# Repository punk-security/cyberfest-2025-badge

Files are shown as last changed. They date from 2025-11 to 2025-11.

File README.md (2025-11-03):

# This is the repo for the CyberNorth CyberFest badge

**This badge was given out at CyberFest conference to all attendees, and had a compass mode so you can always find your way North**

This badge uses UV full colour silk, and we ordered them from JLCPCB using EasyEDA. The PCB was built first with AutoCAD EAGLE, then exported, and imported into EasyEDA by JLCPCB for design updates. We have provided the EasyEDA exports in case you want to import and tweak the designs, or you can order your own as-is using the gerber files :)

Unlike almost all of our other badges, we ordered these partialy assembled. This means that JLCPCB placed some parts for us. We did this as the 3-axis magnometer (which does the compass reading) was tiny and needed a super tiny capacitor too!

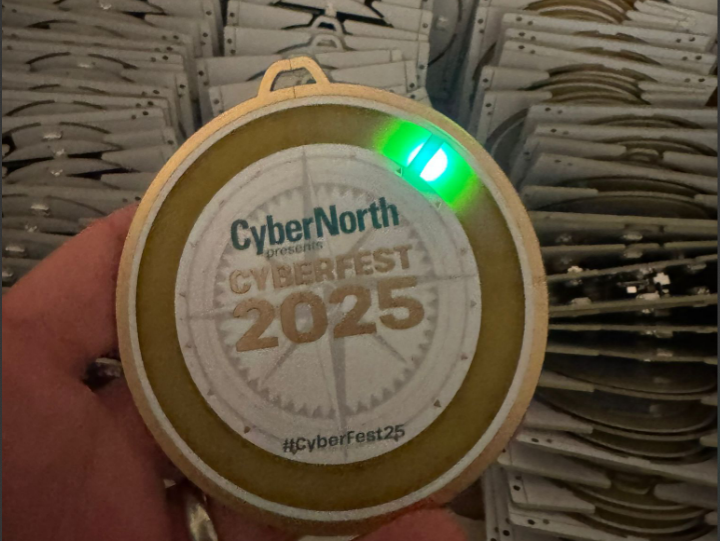
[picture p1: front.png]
PCB Front

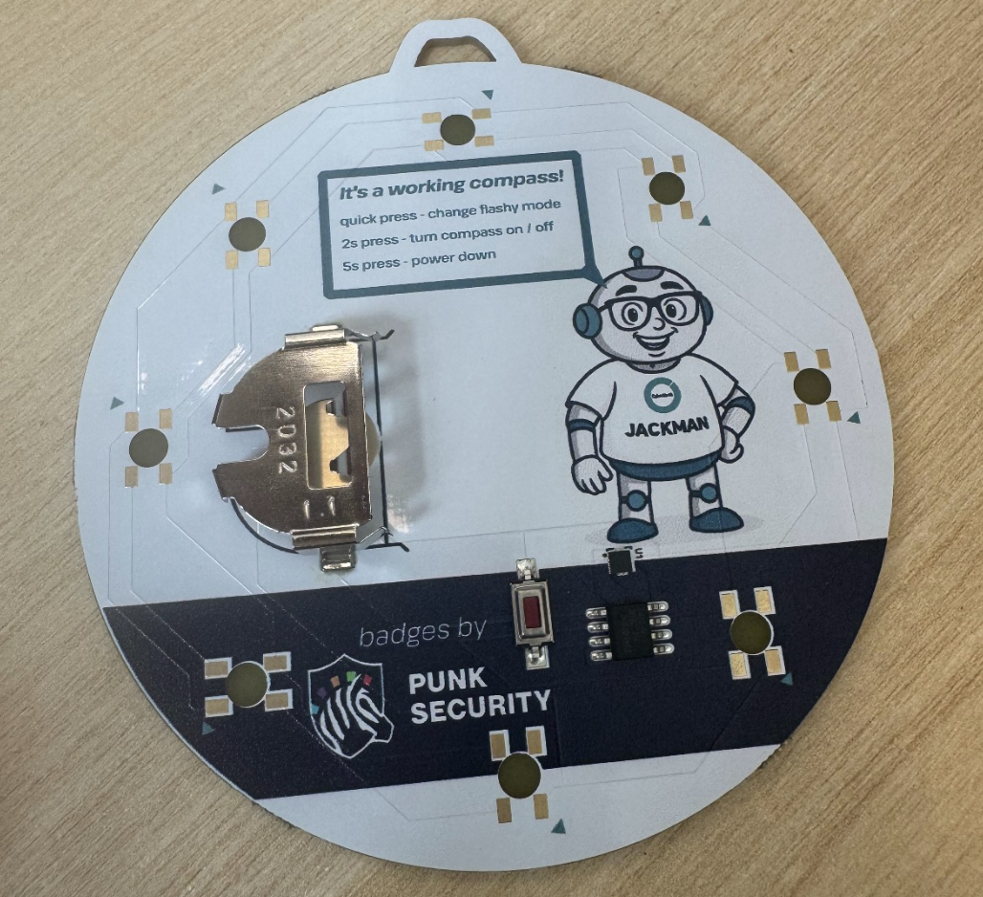
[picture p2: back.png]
PCB Back


Lots of things in this repo:

- EAGLE.brd: The AutoCAD Eagle board design
- EAGLE.sch - The AutoCAD Eagle circuit schematic
- cyberfest-2025.epro - The EasyEDA export, including the front art
- gerber.zip: the file you can upload to JLCPCB and order your own badge, as is
- firmware.ino: the arduino code that powers the badge, which you can modify and flash via the SAO connector

## Bill Of Materials

We sourced some parts direct from JLCPCB, so you may need to tweak footprints when ordering direct. The most notable difference is the coin cell battery clasp, which has smaller "foot" pads. The one provided by JLC was awful and we would recommend replacing it.

Essentially its:

* ATTINY412 microcontroller
* Button - any surface mount button fitting the footprint will work
* CR2032 battery clip  - surface mount not through hole
* Neopixel 5050 addressable LED - Definitely get the right version of these
* LIS2MDLTR - a 3-axis magnetometer (the compass)

## How does it work?

The badge does the usually blinky modes, but also provides a north bearing. To do this, we read the magentic readings from a 3-axis magnometer (LIS2MDLTR)

Compass reading is difficult, as the enviroment is full of intereference. We need to calibrate our readings, so when compass mode is activated we take continous readings for a few seconds. During this time, you should rotate the badge a few times. 

You'll see lots of really tricky code in this repo around compass bearings. Essentially turning magentic readings into a bearing is difficult, and the math to do it takes a lot of flash space. More flash space then we have available actually, so we had to do some funky coding to get a near-enough reading. Our resolution is one of 8 LEDS, so it's a fair trade off!

The current build uses 4082 of 4096 bytes of flash!

## Ordering your own badge

We've uploaded the AutoCAD EAGLE schematic and board design!  You will probably have to do some tweaks to get it working as they're not designed to be standalone exports.

This is then exported to EasyEDA to add the colour print to the boards. The file for that is already in the repo, so you can skip the EAGLE step if you prefer.

We've also uploaded the gerber.zip.  Take this to JLCPCB and you can order your own exact copies of the board :)

## Writing and flashing code!

We use [MegaTinyCore](https://github.com/SpenceKonde/megaTinyCore) for the arduino interface for ATTINY4x2 chips.

Dev and flashing is done within the Arduino IDE ( < v2 ) using a jtag2updi interface, as discussed [here](https://github.com/SpenceKonde/AVR-Guidance/blob/master/UPDI/jtag2updi.md)

We use [these little usb sticks](https://amzn.eu/d/c0lx0wG), with a 4.7k resistor soldered between the Tx and Rx lines.  

### Installing MegaTinyCore dependencies

This board package can be installed via the board manager in arduino. The boards manager URL is:

`http://drazzy.com/package_drazzy.com_index.json`

1. File -> Preferences, enter the above URL in "Additional Boards Manager URLs"
2. Tools -> Boards -> Boards Manager...
3. Wait while the list loads (takes longer than one would expect, and refreshes several times).
4. Select "megaTinyCore by Spence Konde" and click "Install". For best results, choose the most recent version.

### Setting up the IDE

1. Open the file **firmware.ino** in arduino
2. Select tools > Board > megaTinyCore > ATtiny412/402/212/202
3. Select tools > Chip > ATtiny412
4. Select tools > Clock > 16Mhz internal *(we get power issues otherwise)*
5. Select tools > millis > Disabled
5. Select tools > Programmer > SerialUPDI SLOW
6. Select tools > Port > ( pick your COM port)

### Flashing firmware
1. Connect the 3v3 pin to 3v on your usb (maybe wedge it in the battery clip)
2. Connect GND to GND
3. Connect UPDI to the RxD port
4. Click Upload button

## How to solder?

Make sure to line up the dot on the attiny412 with the dot on the board.

*It's much easier if you hold the component in place with one hand, and then solder one pad. Now you can solder the rest of the pads with one hand*

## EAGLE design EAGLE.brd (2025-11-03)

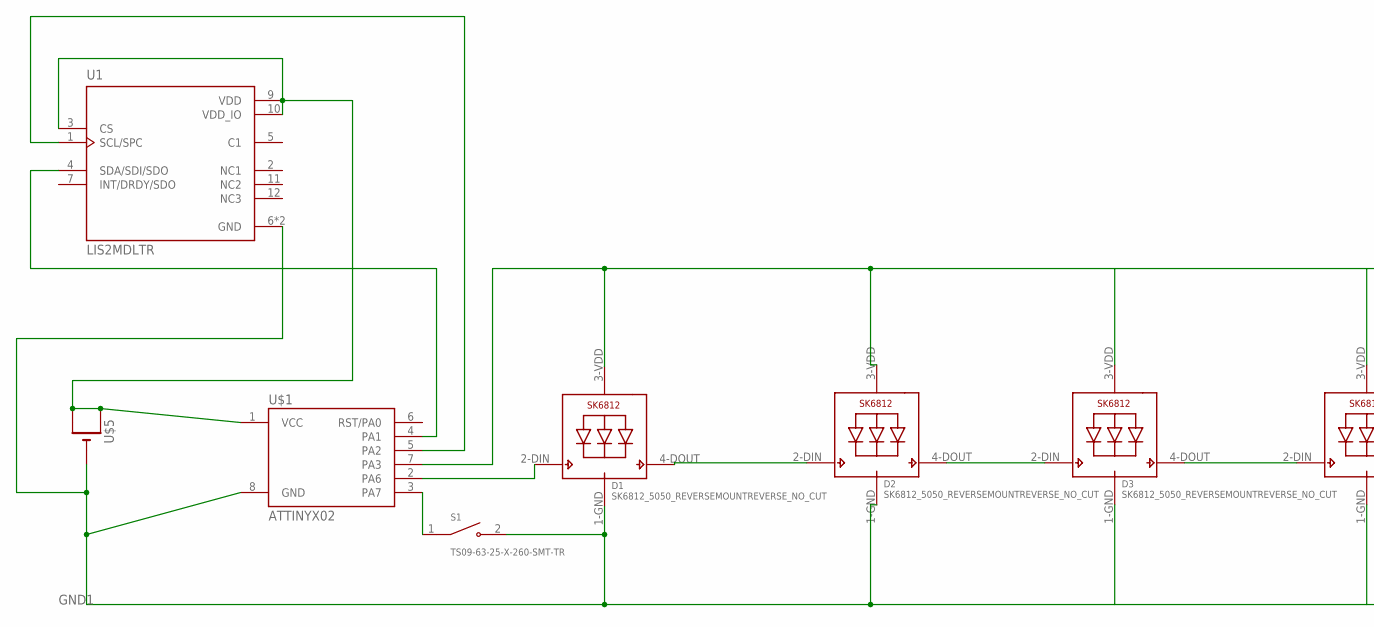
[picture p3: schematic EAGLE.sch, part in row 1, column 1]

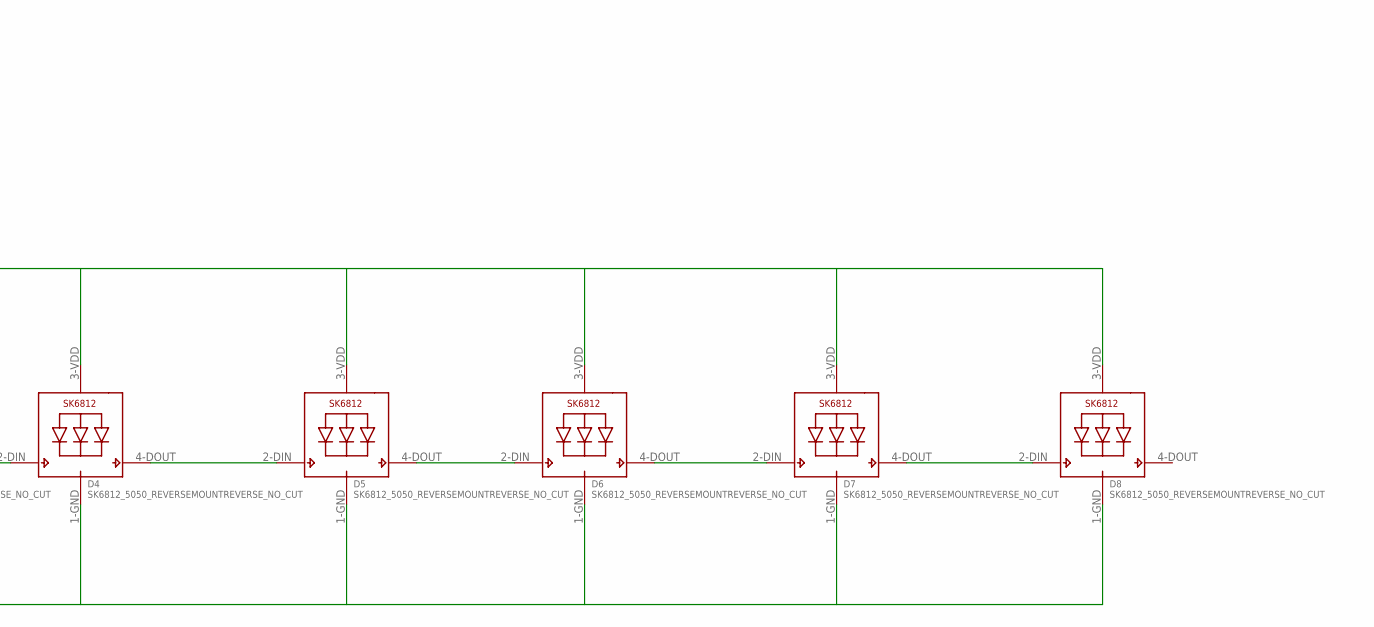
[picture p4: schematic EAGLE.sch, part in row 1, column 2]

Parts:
D1, D2, D3, D4, D5, D6, D7, D8: SK6812_5050_REVERSEMOUNTREVERSE_NO_CUT; SK6812_REVERSE_NO_CUT
S1: TS09-63-25-X-260-SMT-TR; SW_TS09-63-25-X-260-SMT-TR
U1: LIS2MDLTR; PQFN50P200X200X70-12N
U$1: ATTINYX02; SOIC08_JEDEC_150MIL
U$5: CR2032SMT; CR2032-SMD

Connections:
GND1: D1.1-GND (GND), D2.1-GND (GND), D3.1-GND (GND), D4.1-GND (GND), D5.1-GND (GND), D6.1-GND (GND), D7.1-GND (GND), D8.1-GND (GND), S1.2, U1.6 (GND), U1.8 (GND), U$1.8 (GND), U$5.-
unnamed: D1.4-DOUT (DO), D2.2-DIN (DI)
unnamed: D1.2-DIN (DI), U$1.2 (PA6)
unnamed: D3.4-DOUT (DO), D4.2-DIN (DI)
unnamed: D2.4-DOUT (DO), D3.2-DIN (DI)
unnamed: S1.1, U$1.3 (PA7)
unnamed: D4.4-DOUT (DO), D5.2-DIN (DI)
unnamed: D6.4-DOUT (DO), D7.2-DIN (DI)
unnamed: D7.4-DOUT (DO), D8.2-DIN (DI)
unnamed: D5.4-DOUT (DO), D6.2-DIN (DI)
unnamed: U1.1 (SCL/SPC), U$1.5 (PA2)
unnamed: U1.4 (SDA/SDI/SDO), U$1.4 (PA1)
VCC1: U1.3 (CS), U1.9 (VDD), U1.10 (VDD_IO), U$1.1 (VCC), U$5.+$1 (+), U$5.+$2 (+1)
VDD2: D1.3-VDD (VDD), D2.3-VDD (VDD), D3.3-VDD (VDD), D4.3-VDD (VDD), D5.3-VDD (VDD), D6.3-VDD (VDD), D7.3-VDD (VDD), D8.3-VDD (VDD), U$1.7 (PA3)

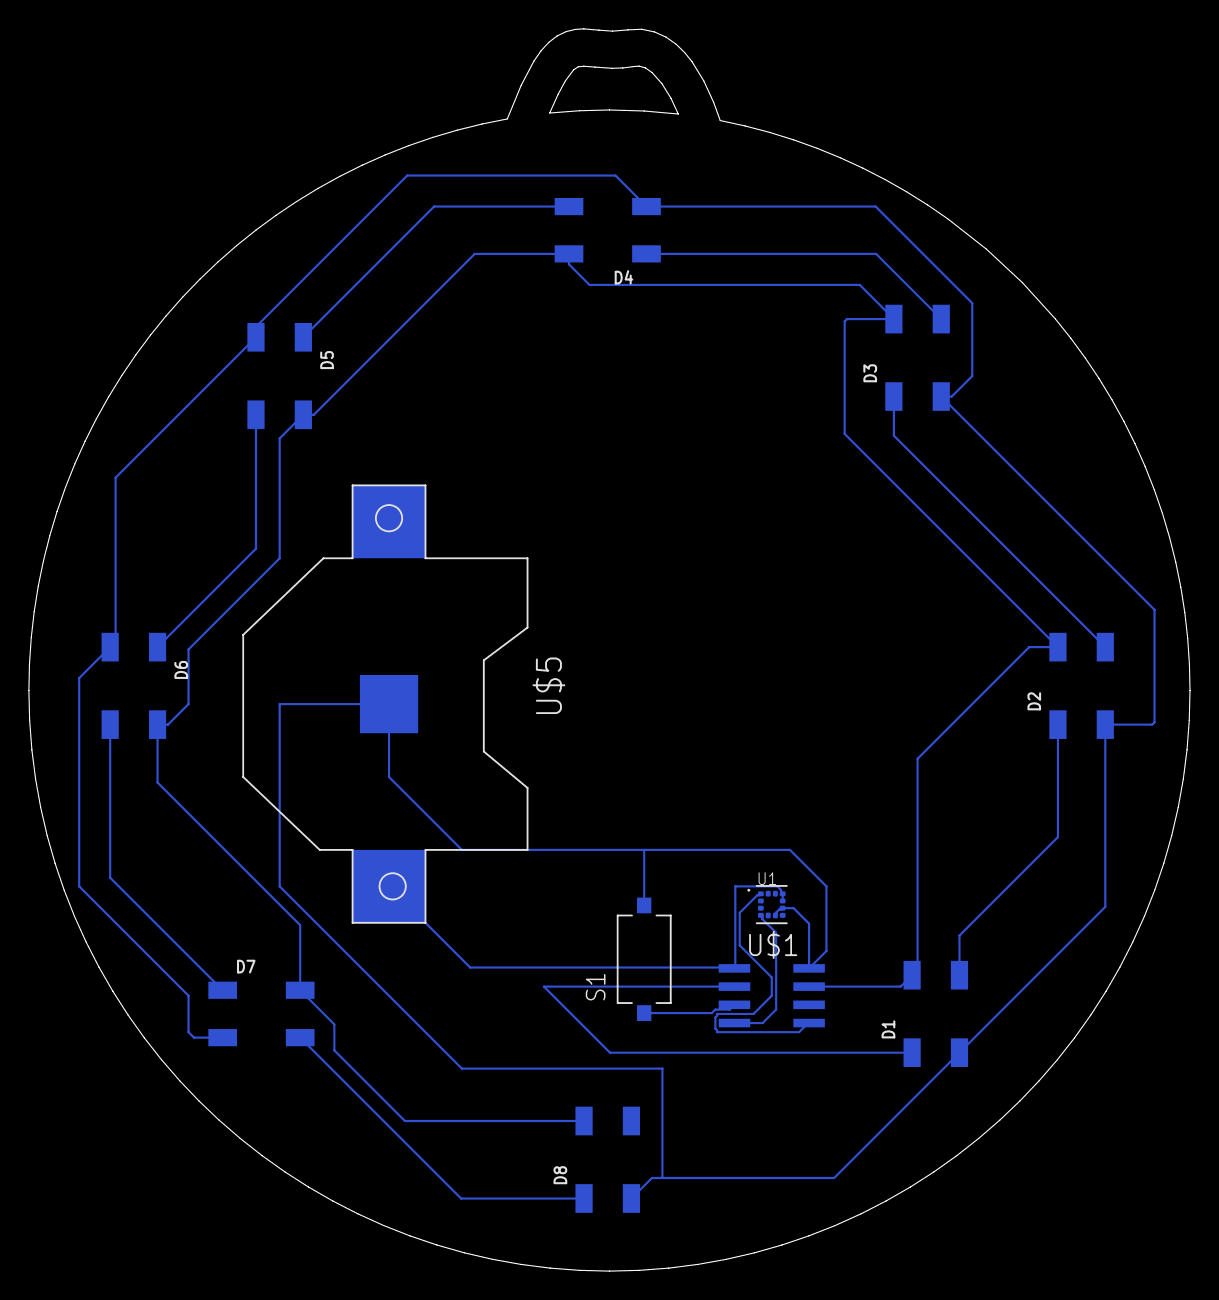
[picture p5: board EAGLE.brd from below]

Board: 2 copper layers, 80.9 x 86.6 mm, 12 parts (12 on the bottom side), 14 nets.

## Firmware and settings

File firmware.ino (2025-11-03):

// BUILD SETTINGS:
// ATTINY412
// disable millis
// run at 16mhz

#define WAKE_TIME_MS 2160000 // Roughly 60 minutes

#include <avr/sleep.h>
#include <avr/io.h>-
#include <avr/pgmspace.h>
#include <tinyNeoPixel_Static.h>
#define NUMLEDS 8
#define BUTTON_PIN PIN_PA7
byte pixels[NUMLEDS * 3];
tinyNeoPixel strip = tinyNeoPixel(NUMLEDS, PIN_PA6, NEO_GRB, pixels);

#define OFF 0,0,0
#define RED 255,0,0
#define GREEN 0,255,0
#define BLUE 0,0,255
#define ORANGE 255,80,0
#define PINK 255,0,180
#define PURPLE 20,0,255
#define OLIVE 2,2,0
#define YELLOW 180,120,0
#define YELLOWGREEN 20,30,20

bool color_switch = false;

uint16_t time_pin_low(uint16_t max_ms)
{
  // blocking for up to max_ms
  if (digitalRead(BUTTON_PIN) == HIGH)
  {
    return(0);
  }
  delay(50); //debounce-
  uint16_t t = 50;
  while(digitalRead(BUTTON_PIN) == LOW)
  {
    delay(5);
    t = t + 5;
    if ( t > max_ms )
      return(max_ms);
  }
  return(t);
}

void setAllPixels(int r, int g, int b, bool show = false)
{
  for (int i = 0; i < NUMLEDS; i++) 
  {
    strip.setPixelColor(i,r,g,b);
  }
  if(show)
    strip.show();
}

void RTC_init()
{
  /* Initialize RTC: */
  while (RTC.STATUS > 0)
  {
    ;                                   /* Wait for all register to be synchronized */
  }
  RTC.CLKSEL = RTC_CLKSEL_INT1K_gc;    /* 1kHz Internal Ultra-Low-Power Oscillator (OSCULP32K) */
}

void mini_sleep( uint8_t period = RTC_PERIOD_CYC16_gc)
{
  // default timer is about 16ms
  RTC.PITINTCTRL = RTC_PI_bm;  // Enable RTC interrupt
  RTC.PITCTRLA = period | RTC_PITEN_bm;
  set_sleep_mode(SLEEP_MODE_PWR_DOWN);
  sleep_enable();
  sleep_cpu();
  RTC.PITINTCTRL = ~(RTC_PI_bm); // Disable RTC interrupt
}

ISR(RTC_PIT_vect)
{
  RTC.PITINTFLAGS = RTC_PI_bm;  // Clear RTC interrupt flag otherwise keep coming back here
}

ISR(PORTA_PORT_vect) {
  PORTA.INTFLAGS = PORT_INT7_bm; // Clear Pin 7 interrupt flag otherwise keep coming back here
}


void sleep()
{
  writeReg(0x60, 0x93); // 10010000 TEMP + LOW POWER + 10HZ + Idle
  set_sleep_mode(SLEEP_MODE_PWR_DOWN);
  PORTA.PIN7CTRL = PORT_PULLUPEN_bm | PORT_ISC_LEVEL_gc; // enable pullup and interrupt
  digitalWrite(PIN_PA3, LOW); // turn off LED power rail
  sleep_enable();
  sleep_cpu();
  // sleep resumes here
  PORTA.PIN7CTRL = PORT_PULLUPEN_bm; // renable pullup but no interrupt
  digitalWrite(PIN_PA3, HIGH);  // turn on LED power rail
  lis2mdl_begin();
}

int police(int n)
{
  setAllPixels(40,0,0);
  if (n & 1)
  {
    strip.setPixelColor(0,0,0,255);
    strip.setPixelColor(2,0,0,255);
    strip.setPixelColor(4,0,0,255);
    strip.setPixelColor(6,0,0,255);
  }
  else
  {
    strip.setPixelColor(1,0,0,255);
    strip.setPixelColor(3,0,0,255);
    strip.setPixelColor(5,0,0,255);
    strip.setPixelColor(7,0,0,255);
  }
  strip.show();
  return 200;
}

int phase(int n)
{
  setAllPixels(0,0,0);
  switch(n % 8)
  {
    case 0:
      strip.setPixelColor(1,0,255,0);
      break;
    case 1:
      strip.setPixelColor(0,0,255,0);
      strip.setPixelColor(2,0,255,0);
      break;
    case 2:
      strip.setPixelColor(7,0,255,0);
      strip.setPixelColor(3,0,255,0);
      break;
    case 3:
      strip.setPixelColor(6,0,255,0);
      strip.setPixelColor(4,0,255,0);
      break;
    case 4:
      strip.setPixelColor(5,0,255,0);
      break;
    case 5:
      strip.setPixelColor(6,0,255,0);
      strip.setPixelColor(4,0,255,0);
      break;
    case 6:
      strip.setPixelColor(7,0,255,0);
      strip.setPixelColor(3,0,255,0);
      break;
    case 7:
      strip.setPixelColor(0,0,255,0);
      strip.setPixelColor(2,0,255,0);
      break;
  }
  strip.show();
  return 150;
}

int chase(int n, int r, int g, int b)
{
  uint8_t i = n % 8;
  setAllPixels(OFF);
  strip.setPixelColor(i,r,g,b);
  strip.show();
  return 80;
}

int chase2(int n, int r, int g, int b)
{
  uint8_t i = n % 8;
  uint8_t i2 = (n + 4) % 8;
  setAllPixels(OFF);
  strip.setPixelColor(i,r,g,b);
  strip.setPixelColor(i2,r,g,b);
  strip.show();
  return 200;
}

int cycle(int n)
{
  uint8_t i = n % 5;
  switch(i) {
   case 0:
    setAllPixels(RED,true);
    break;
   case 1:
    setAllPixels(GREEN,true);
    break;
   case 2:
    setAllPixels(YELLOW,true);
    break;
   case 3:
    setAllPixels(PURPLE,true);
    break;
   case 4:
    setAllPixels(BLUE,true);
    break;
  }
  return 100;
}

#include <Wire.h>

static const uint8_t LIS2MDL_ADDR = 0x1E; 

void writeReg(uint8_t reg, uint8_t val) {
  Wire.beginTransmission(LIS2MDL_ADDR);
  Wire.write(reg);
  Wire.write(val);
  Wire.endTransmission();
}

uint8_t readReg(uint8_t reg) {
  uint8_t pins = Wire.checkPinLevels();
  if ((pins & 0x03))
  {
    strip.setPixelColor(3,1,0,0);strip.show();
  }
  Wire.beginTransmission(LIS2MDL_ADDR);
  Wire.write(reg);
  Wire.endTransmission();
  Wire.requestFrom(LIS2MDL_ADDR, (uint8_t)1);
  return Wire.read();
}

void readBytes(uint8_t startReg, uint8_t *buf, uint8_t len) {
  // Set MSB of subaddress for auto-increment (ST convention)
  Wire.beginTransmission(LIS2MDL_ADDR);
  Wire.write(startReg | 0x80);
  Wire.endTransmission(false);
  Wire.requestFrom(LIS2MDL_ADDR, len);
  for (uint8_t i = 0; i < len; i++) buf[i] = Wire.read();
}

bool lis2mdl_begin() {
  // Setup the 3-axis magnometer for low power continous mode
  writeReg(0x60, 0x20);  // SOFT_RST=1
  delay(10);
  writeReg(0x60, 0x00);  // clear reset
  delay(10);
  writeReg(0x60, 0x90); // 10010000 TEMP + LOW POWER = 10HZ
  return true;
}

void setup()
{
  // Power save
  // http://www.technoblogy.com/show?2RA3
  // https://github.com/SpenceKonde/megaTinyCore/blob/master/megaavr/extras/PowerSave.md
  ADC0.CTRLA &= ~ADC_ENABLE_bm; // Disable ADC
  pinMode(PIN_PA6, OUTPUT);
  // UPDI does not need setting (PA0)

  // Pin setup
  pinMode(PIN_PA3, OUTPUT);
  pinMode(PIN_PA7, INPUT_PULLUP);
  digitalWrite(PIN_PA3, HIGH);

  Wire.usePullups();
  Wire.begin();
  Wire.setClock(100000L);
  if (!lis2mdl_begin()) {
    strip.setPixelColor(3,255,0,0);
  }
  else
  {
    strip.setPixelColor(3,0,255,0);
  }
  strip.show();
  RTC_init();
}

int16_t offX=0, offY=0;
int16_t minX=32767, maxX=-32768, minY=32767, maxY=-32768;

void accumulateCal(int16_t x, int16_t y){
  if (x<minX) minX=x; if (x>maxX) maxX=x;
  if (y<minY) minY=y; if (y>maxY) maxY=y;
}

void finishCal() {
  offX = (int16_t)((maxX + minX)/2);
  offY = (int16_t)((maxY + minY)/2);
}

void lis2mdl_readRaw(int16_t &mx, int16_t &my) {
  uint8_t buf[4];
  readBytes(0x68, buf, 4);  // OUTX_L .. OUTZ_H
  int16_t x = (int16_t)((uint16_t)buf[1] << 8 | buf[0]);
  int16_t y = (int16_t)((uint16_t)buf[3] << 8 | buf[2]);
  mx = x;
  my = y;
}

// Integer-only compass heading in whole degrees [0..359]
uint16_t computeHeading(int16_t mx, int16_t my) {
  
  int32_t x = mx, y = my;

  // Guard: undefined when both are zero
  if (x == 0 && y == 0) return 0;

  int32_t ay = (y < 0) ? -y : y;   // |y|
  int32_t angle_cdeg;              // angle in centi-degrees (deg*100)

  if (x >= 0) {
    int32_t denom = x + ay;        // >= 0
    if (denom == 0) {
      angle_cdeg = 0;              // x==0 & y==0 already handled; pick 0°
    } else {
      // ≈ 45° − 45° * (x − |y|)/(x + |y|)
      angle_cdeg = 4500 - (4500 * (x - ay)) / denom;
    }
  } else {
    // x < 0
    int32_t denom = ay - x;        // > 0
    // ≈ 135° − 45° * (x + |y|)/( |y| − x )
    angle_cdeg = 13500 - (4500 * (x + ay)) / denom;
  }

  if (y < 0) angle_cdeg = -angle_cdeg;

  // Normalize to [0, 36000)
  angle_cdeg %= 36000;
  if (angle_cdeg < 0) angle_cdeg += 36000;

  // Convert to whole degrees. Important: guard 360 after rounding.
  uint16_t deg = (uint16_t)((angle_cdeg + 50) / 100); // round to nearest
  if (deg >= 360) deg -= 360;                         // avoid 360 wrap
  return deg;
}

int display_north()
{
    setAllPixels(OFF,true);
    int16_t rx, ry;
    int heading;
    int pixel;
    lis2mdl_readRaw(rx, ry);
    accumulateCal(rx, ry);
    finishCal();
    rx -= offX;
    ry -= offY;
    heading = computeHeading(rx >> 3, ry >> 3 );

    uint8_t sector = (heading + 22) / 45;
    if (sector >= 8) sector = 0;

    const uint8_t sectorToPixel[8] = {
      1, // sector 0: 0°–22°
      0, // sector 1: 23°–67°
      7, // sector 2: 68°–112°
      6, // sector 3: 113°–157°
      5, // sector 4: 158°–202°
      4, // sector 5: 203°–247°
      3, // sector 6: 248°–292°
      2  // sector 7: 293°–337°, 338–359 wraps to sector 0 again (→ pixel 1)
    };

    pixel = sectorToPixel[sector];

    if (color_switch)
    {
      strip.setPixelColor(pixel, GREEN);
    }
    else
    {
      strip.setPixelColor(pixel, YELLOW);
    }
    
    strip.show();
    return(20);
}

void loop()
{
  uint8_t mode = 0;
  uint8_t interval;
  uint16_t button_low_time = 0;
  uint32_t total_interval = 0;
  strip.begin();
  uint8_t i = 0;
  while(true)
  {
    if ( mode == 0)
    {
      interval = chase(i,0,100,255);
    }
    else if ( mode == 1 )
    {
      interval = chase2(i, YELLOW);
    }
    else if ( mode == 2)
    {
      interval = police(i);
    }
    else if ( mode == 3)
    {
      interval = cycle(i);
    }
    else if ( mode == 4)
    {
      interval = phase(i);
    }
    else if ( mode == 5)
    {
      interval = chase(i,RED);
    }
    else if ( mode == 9)
    {
      mode = 0;
      continue;
    }
    else if ( mode == 10)
    {
      // COMPASS MODE
      interval = display_north();
    }
    else
    {
      mode++;
    }
    i++;
    // This section breaks down the sleep interval to catch button presses
    total_interval = total_interval + interval;
    while(interval > 0)
    {
      mini_sleep();
      interval = interval - 10;
      button_low_time = time_pin_low(2000);
      if (button_low_time > 100)
      {
       /*
       * MAIN MENU
       * NO PRESS = CONTINUE
       * SHORT PRESS = CHANGE FLASHY MODE
       * LONG PRESS = SLEEP
       */
        if (button_low_time > 1200)
        {
          setAllPixels(RED,true);
          while(digitalRead(BUTTON_PIN) == LOW)
          {
            // WAIT FOR RELEASE BEFORE SLEEPING otherwise we wake back up!
            delay(5);
          }
          delay(50); //DEBOUNCE
          sleep();
        }
        else if (button_low_time > 400)
        {
          // SWITCH MODE
          if (mode == 10)
          {
            // If we are in compass mode, leave it
            mode = 0;
            continue;
          }
          // ELSE< setup and enter compass mode
          mode = 10;
          minX=32767;
          maxX=-32768;
          minY=32767;
          maxY=-32768;
          if (color_switch)
          {
            setAllPixels(GREEN,true);
          }
          else
          {
            setAllPixels(YELLOW,true);
          }
          
          for (uint8_t i=0; i<250; i++) {
            int16_t rx, ry; lis2mdl_readRaw(rx, ry);
            accumulateCal(rx, ry);
            mini_sleep();
          }
          finishCal();
          continue;
        }
        else
        {
          if (mode != 10) mode++;
          color_switch = !color_switch;
        }
        // reset timer
        i = 0;
        total_interval = 0;
      }

    }
    // At the end of each interval, see if we need to sleep
    if (total_interval > WAKE_TIME_MS)
    {
      total_interval = 0;
      i = 0;
      sleep();
      if (mode == 10) mode = 0; // If in compass mode, leave it
    }
  }
}
